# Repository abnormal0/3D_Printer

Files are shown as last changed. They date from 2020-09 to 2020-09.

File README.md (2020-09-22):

# 3D_Printer

3D Printer Designing @ June 2019

This is a project I did in 2019, which is a 3D printer, I used SolidWorks software to independently design the mechanical structure of the 3D printer, assisted in the design of the printer's motherboard circuit using Altium Designer, and assisted in the use of Clion as a IDE for embedded programming (C++), finally used Repetier-Host to test and print, the results are good.

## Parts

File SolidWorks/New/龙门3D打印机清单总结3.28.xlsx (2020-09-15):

关于现用200*200的3D打印机所需材料的总结
淘宝店 | 类型 | 规格 | 需要个数 | 单价 | 实际采购数量 | 总价 | 备注1 | 备注2 | 常用淘宝店家及链接
锦铝金属 (200以上开普票、以下不开） | 角块 | 2020 90度 | 8 | 1.5 | 8 | 12 |  |  | https://detail.tmall.com/item.htm?id=562060542375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
 |  | 2028 90度 | 4 | 1.8 | 4 | 7.2 | 垫底放电源备用
 |  | 45度 | 4 | 2.7 | 4 | 10.8 |  |  | https://detail.tmall.com/item.htm?id=562149318211&ns=1&abbucket=15&skuId=3701328155033
 | 船型螺母 | M4 | 4 | 0.3 | 10 | 3 |  |  | https://detail.tmall.com/item.htm?id=562124503053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
 |  | M5 | 85 | 0.35 | 100 | 35
 | 螺丝 | M4*30mm |  | 0.2 | 15 | 3 | 246.14 |  | https://detail.tmall.com/item.htm?id=563383555429&rn=71779688bedd88fad3f17ce4a9ea42f8&abbucket=8
 |  | M4*20mm |  | 0.2 | 20 | 4
 |  | M4*25mm |  | 0.2 | 10 | 2
 |  | M5*12mm |  | 0.15 | 70 | 10.5 | 用于铝型材固定
 |  | M5*8mm |  | 0.15 | 30 | 4.5
 |  | M5*16mm |  | 0.2 | 10 | 2
 |  | M5*10mm |  | 0.15 | 30 | 4.5
 | 覆盖板 | 2020 |  | 0.5 | 10 | 5 |  |  | https://detail.tmall.com/item.htm?id=562234523850&rn=545b0d162a0ad1bcf5be1794c23a67da&skuId=3694715830944
 |  | 2040 |  | 0.6 | 2 | 1
 | 角铝 | 80*80*6*1 |  |  | 1
 | 运费 |  |  |  |  | 9.4
瑞耐斯动力机械 （不开） | 立式轴承座 | KP08 | 10 | 2.85 | 10 | 28.5 |  |  | https://item.taobao.com/item.htm?spm=a1z10.1-c.w4004-18394139469.6.71c232e7foBqiQ&id=576786036687
 | 直线滑动滑块 | SCS8UU | 4 | 6.5 | 4 | 26 |  |  | https://item.taobao.com/item.htm?spm=a1z0d.7625083.1998302264.5.e4ab4e69x0ZOVJ&id=38524866174
 | 运费 |  |  |  |  | 10
坚威 （普票） | 外六角螺丝 | M3*8mm |  | 1.58 | 3 | 4.74 |  | 一包（10粒） | https://detail.tmall.com/item.htm?id=19278041723&rn=027d145cce653adb819a6ab926daf2c6&abbucket=8
 |  | M3*10mm |  | 1.68 | 2 | 3.36
 |  | M3*12mm |  | 1.78 | 2 | 3.56
 |  | M3*20mm |  | 2.28 | 1 | 2.28
 |  | M3*40mm |  | 3.7 | 1 | 3.7
 | 蝶形螺母 | M3 |  | 2 | 1 | 2 |  | 一包（10粒） | https://detail.tmall.com/item.htm?id=15466106343&rn=f1e7168ab5e2a042e206138b3402bcc0&abbucket=8
 | 外六角螺母 | M3 |  | 1.88 | 1 | 1.88 |  | 一包（20粒） | https://detail.tmall.com/item.htm?id=21253683169&rn=9e7bfd596e6b2c989f7e7b583f77c012&abbucket=8
 |  | M4 |  | 1.88 | 1 | 1.88
 |  | M5 |  | 1.28 | 2 | 2.56 |  | 一包（10粒）
 | 垫片 | M3*7*0.5mm |  | 1.38 | 1 | 1.38 | 限制：外径小于7.2mm | 一包（50粒） | https://detail.tmall.com/item.htm?id=18212096844&rn=48a5eeb54cd6bf01022148591b0d27cf&abbucket=8
 |  | M4*12*1mm |  | 1.88 | 1 | 1.88 | 限制：厚度为1mm
 |  | M5*10*1mm |  | 2.88 | 2 | 5.76 | 限制：厚度为1mm
 | 运费 |  |  |  |  | 5
大熊 （500以上开普票、以下开收据） | 电机座 | 42适配 | 2 | 1.85 | 2 | 3.7 | 第一件1.35 |  | https://item.taobao.com/item.htm?spm=a1z10.3-c.w4002-16808717495.11.21541f0fLYdBOu&id=550518493187
 | 挤出机套件 | 远程 1.75mm耗材 | 1 | 18 | 1 | 18 | 右手 |  | https://item.taobao.com/item.htm?spm=a1z10.3-c.w4002-16808717495.10.1a861f0f07pwb7&id=580259659280
 | 挤出电机 | 42 | 1 | 21 | 1 | 21 | 500mN扭力 |  | https://item.taobao.com/item.htm?spm=a1z10.5-c.w4002-16808717485.47.3ff449e79ndDr1&id=573837986187
 | 丝杆 | 8*450mm | 1 | 12.5 | 1 | 12.5 | 导程8mm 配丝杆螺母 |  | https://item.taobao.com/item.htm?spm=a1z10.5-c.w4002-16808717485.9.539649e7rQJ0iJ&id=549235947200
 |  | 8*400mm | 1 | 10.5 | 1 | 10.5
 |  | 8*350mm | 2 | 10 | 2 | 20 |  | 第一件9
 | 喷嘴套件 | V5,1.75*0.4mm | 1 | 22 | 1 | 22 | 远程 |  | https://item.taobao.com/item.htm?spm=a1z10.5-c.w4002-16808717485.23.4f0e3d3eUsWbog&id=566572427613
 | 光轴架 | 8mm | 11 | 2.05 | 11 | 22.55 | 第一件1.6 |  | https://item.taobao.com/item.htm?spm=a1z10.5-c.w4002-16808717485.12.63eb43actElVk8&id=549132170883
 |  | 16mm | 1 | 3.09 | 1 | 3.09
 | 同步轮 | 20齿 内径8 | 2 | 1.19 | 2 | 2.38 | 第一件0.69 |  | https://item.taobao.com/item.htm?spm=a1z10.3-c.w4002-16808717495.12.2b061f0fqClVBx&id=548608976808
 |  | 20齿 内径5 | 1 | 2.5 | 1 | 2.5 | 第一件2.5 |  | https://item.taobao.com/item.htm?spm=a1z10.5-c.w4002-16808717485.17.38405e43pdZeVO&id=548682226471
 |  | 不带齿 内径8 | 1 | 2.5 | 1 | 2.5
 | 同步带 | 600 | 1 | 4 | 1 | 4 |  |  | https://item.taobao.com/item.htm?spm=a1z10.5-c.w4002-16808717485.18.35847656tHOplc&id=548694206862
 | 丝杆螺母 | 导程8mm | 5 | 2.9 | 2 | 5.8 | 丝杆配了3个 |  | https://item.taobao.com/item.htm?spm=a1z10.5-c.w4002-16808717485.9.539649e7rQJ0iJ&id=549235947200
 | 热床 | 214*214 | 1 | 23 | 1 | 23 |  |  | https://item.taobao.com/item.htm?spm=a1z10.5-c.w4002-16808717485.35.413f77bfbgHAVP&id=550002989379
 | 联轴器 | 5mm*8mm | 2 | 2 | 2 | 4 | 第一件1.5 |  | https://item.taobao.com/item.htm?spm=a1z10.5-c.w4002-16808717485.22.6e7749e7yMqgn5&id=548882345967
 | 玻璃板 | 214*214*3mm | 1 | 9.5 | 1 | 9.5 |  |  | https://item.taobao.com/item.htm?spm=a1z10.5-c.w4002-16808717485.23.413f77bfbgHAVP&id=550065035441
 | 风扇 | 40*40*10mm | 1 | 1.3 | 1 | 1.3 |  |  | https://item.taobao.com/item.htm?spm=a1z10.5-c.w4002-16808717485.13.7a5c3b27watjqI&id=550262768093
 | 小猪佩奇风扇 |  | 1 | 11 | 1 | 11 |  |  | https://item.taobao.com/item.htm?spm=a1z10.5-c.w4002-16808717485.25.48bd3b27UXdbWK&id=550381735888
 | PE包线管 | 8mm | 1 | 3.2 | 1 | 3.2 |  |  | https://item.taobao.com/item.htm?spm=a1z10.3-c.w4002-16808717495.13.3cb31f0flchhTB&id=552765753763
 | 加热块套 | 黄 | 1 | 3 | 1 | 3 |  |  | https://item.taobao.com/item.htm?spm=a1z10.5-c.w4023-16808717484.7.6e7749e7yMqgn5&id=568588751287
 | 螺母座 | 内径8 | 4 | 6.58 | 4 | 26.32 | 第一件4.7 |  | https://item.taobao.com/item.htm?spm=a1z10.3-c.w4002-16808717495.9.7ffa1f0fHKth8f&id=564571287204
 | 椭圆直线轴承 | 内径8外径15 | 2 | 6.35 | 2 | 12.7 | 第一件5.6 |  | https://item.taobao.com/item.htm?spm=a1z10.3-c.w4002-16808717495.21.4c0b1f0fgFqwsL&id=557921686489
 | 氟龙管 | 2*3mm | 1 | 1.6 | 1 | 1.6 | 一份1m | 第一份1.6 | https://item.taobao.com/item.htm?spm=a1z0d.6639537.1997196601.3.7ea37484DQyn6M&id=549385220360
 | 电源 | 12V，20A，250W | 1 | 43 | 1 | 43 |  |  | https://item.taobao.com/item.htm?spm=a1z10.3-c.w4002-16808717495.18.60191f0fSX5zlX&id=550475946797
 | 运费 |  |  |  |  | 20
德西克 （普票） | 限位开关 | L型 | 2 | 18 | 3 | 54 | 5个包邮 |  | https://item.taobao.com/item.htm?id=580136528550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
 |  | U型 | 1 | 15 | 2 | 30
德轩电机 （普票） | 电机 | 42*60mm | 3 | 55 | 3 | 165 | 扭力0.9Nm，电流1.7A，引线30cm | 下单备注需要的电流 | https://item.taobao.com/item.htm?spm=a1z0d.6639537.1997196601.204.70377484EOUPLk&id=542770576889
 | 运费 |  |  |  |  | 11
奥格 （不开） | 光轴 | 8*375mm | 2 | - | 2 | 30 |  |  | https://item.taobao.com/item.htm?spm=a1z0d.6639537.1997196601.59.70377484EOUPLk&id=567224102575
 |  | 8*500mm | 2 | - | 2
 |  | 8*420mm | 2 | - | 2
东粤有色金属 （普票） | 铝板 | 20*60*2 | 2 | - | 实际采购300mm*60*2 |  | z轴底部轴承座垫高 | 先不买
 |  | 42*60*2 | 1 | - |  |  | 电机安装座
 |  | 95*40*2 | 2 | - | 实际采购250*40*2 |  | z轴顶部轴承座装配
 |  | 30*42*4 | 2 | - | 实际采购30*200*4 |  | x轴，连接底板和丝杆
 |  | 218*218*4 | 1 | - | 实际采购218*218*4 |  | 底板
东莞厂家 | 2020铝型材 | 290 | 2 |  |  |  | 底面宽
 |  | 490 | 2 |  |  |  | 底面长
 |  | 300 | 2 |  |  |  | 高
 |  | 420 | 1 |  |  |  | 龙门
 |  | 220 | 2
 |  | 188 | 1
 |  | 45度（210mm）
 | 4020铝型材 | 420 | 1 |  |  |  | 底
 | 角块 | 2028,90度角块 | 8
 | 步进电机驱动 | 4988 |  |  |  |  | 精度较低，适用于Z轴以及挤出机
 |  | 8825 |  |  |  |  | 精度较高，适用于X,Y轴
 | 5A大电流驱动 | LV8727
合计： |  |  |  |  |  | 817.52
附：未算运费和发票

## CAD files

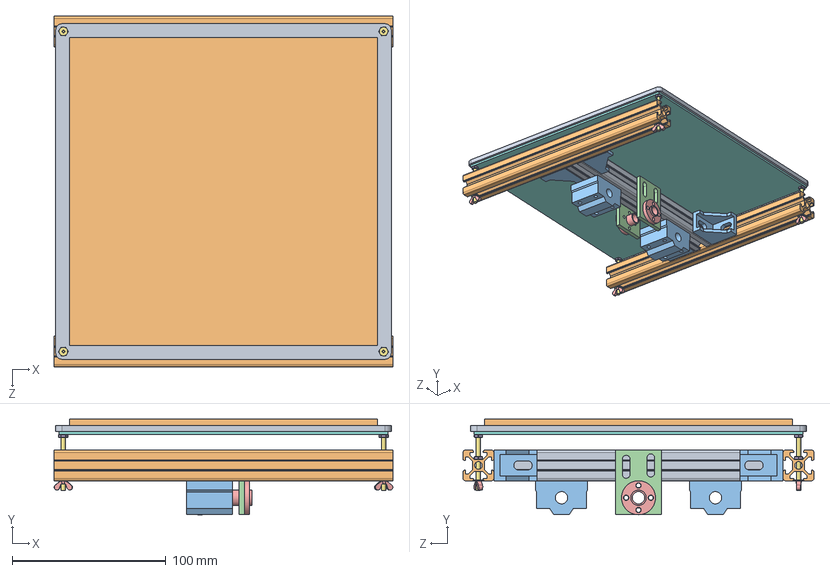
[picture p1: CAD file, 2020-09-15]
SolidWorks/New/底板装配.SLDASM
220.0 x 62.1 x 228.0 mm
2020角码 x 4
M3垫片 x 4
M3蝶形螺母 x 4
M3外六角螺母 x 8
M3_40mm外六角螺丝 x 4
热床
底板
玻璃板200-200-4
直线光杆滑轨 x 2
x轴铝片 x 2
丝杆螺母 x 2

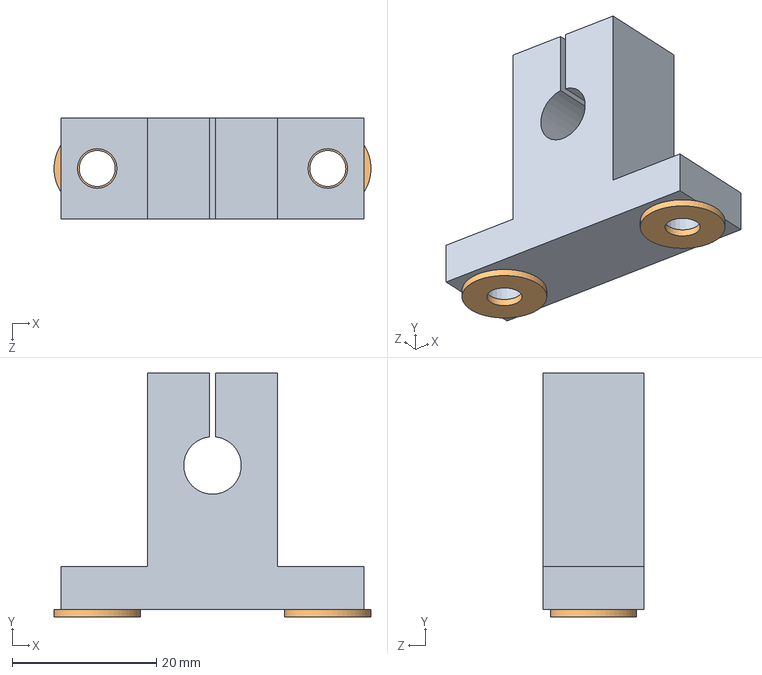
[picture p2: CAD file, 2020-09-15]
SolidWorks/New/光杆架垫片装配.SLDASM
44.0 x 33.8 x 14.0 mm
光杆架
光杆架垫片 x 2

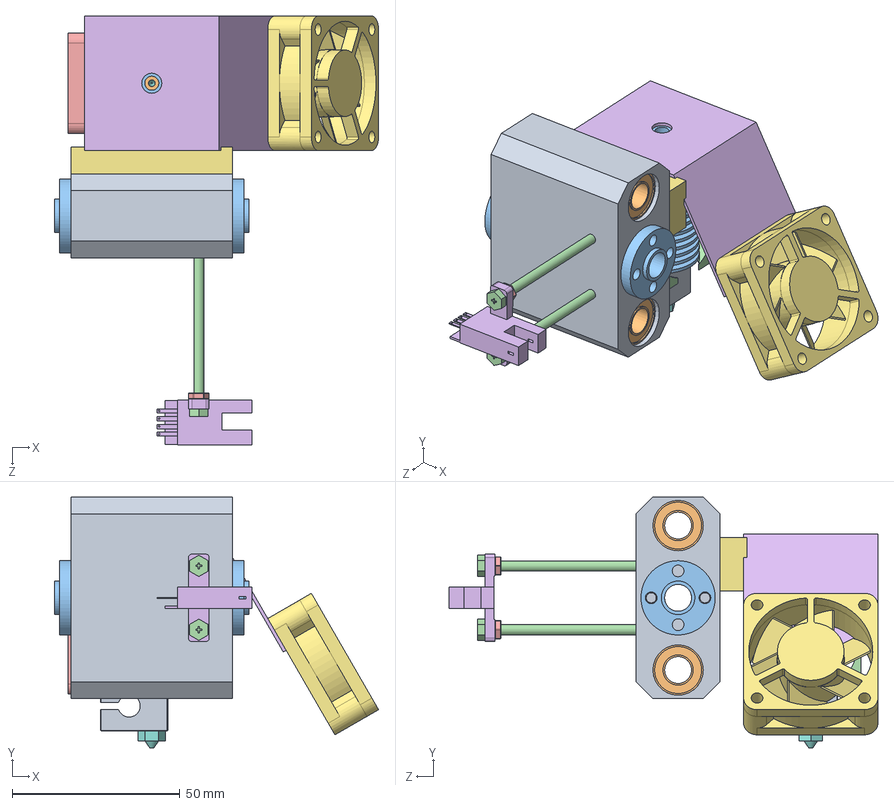
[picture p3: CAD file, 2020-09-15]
SolidWorks/New/y轴装配.SLDASM
96.5 x 74.7 x 127.7 mm
喷嘴固定件
直线轴承 x 2
丝杆螺母 x 2
M3_50mm外六角螺丝 x 2
M3外六角螺母 x 2
光电限位开关
喷头安装座
Nozzle 0.3mm^喷头装配
Heater_Block^喷头装配
Heatbreak^喷头装配
Heatsink^喷头装配
风扇固定
风扇3010
风扇固定片
风扇

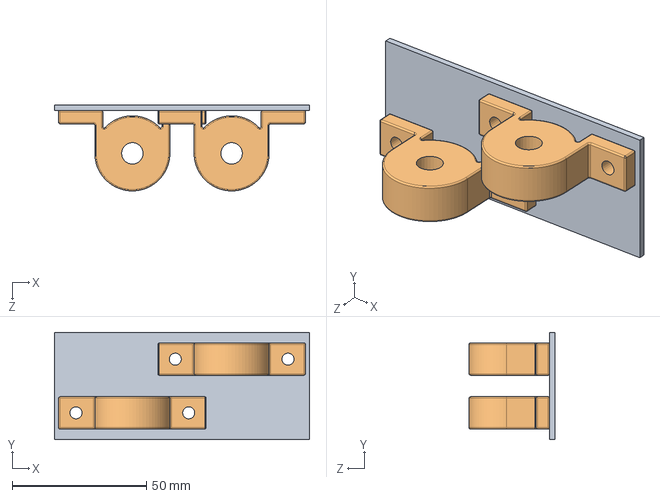
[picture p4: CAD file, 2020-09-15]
SolidWorks/New/立式轴承座右上装配.SLDASM
95.0 x 40.0 x 32.0 mm
立式轴承座右铝片
立式轴承座 x 2

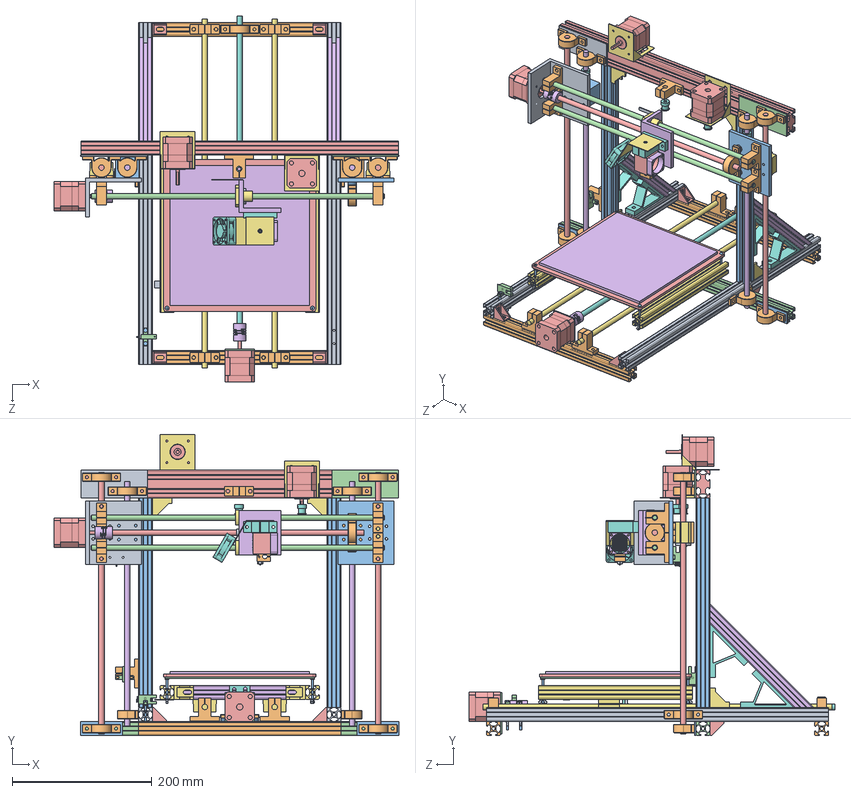
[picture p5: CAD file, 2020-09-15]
SolidWorks/New/新建打印机装配.SLDASM
494.0 x 431.3 x 524.0 mm
2020角码 x 8
2020角码-45度 x 4
立式轴承座左铝片
立式轴承座 x 10
立式轴承座下铝片 x 2
立式轴承座右铝片
小角件 x 6
M3垫片 x 6
M3蝶形螺母 x 6
M3外六角螺母 x 12
M3_40mm外六角螺丝 x 6
热床
底板
玻璃板200-200-4
直线光杆滑轨 x 4
x轴铝片 x 2
丝杆螺母 x 5
光杆架 x 10
光杆架垫片 x 26
42固定铝型材
42 motor x 4
联轴器 5-8-25 x 2
光杆x轴 x 2
丝轴x轴（无螺纹）
角铝
M4垫片 x 8
螺母座z轴限位
光电限位开关 x 3
光杆z轴 x 2
丝轴z轴（无螺纹） x 2
电机座 x 2
2GT-20齿同步轮 x 4
x轴限位片
螺母座
角铝右侧
光杆Y轴 x 2
丝轴y轴（无螺纹）
角铝中间
椭圆直线轴承 x 2
喷头安装座
Nozzle 0.3mm^喷头装配
Heater_Block^喷头装配
Heatbreak^喷头装配
Heatsink^喷头装配
风扇固定
风扇3010
风扇固定片
风扇
y轴限位片

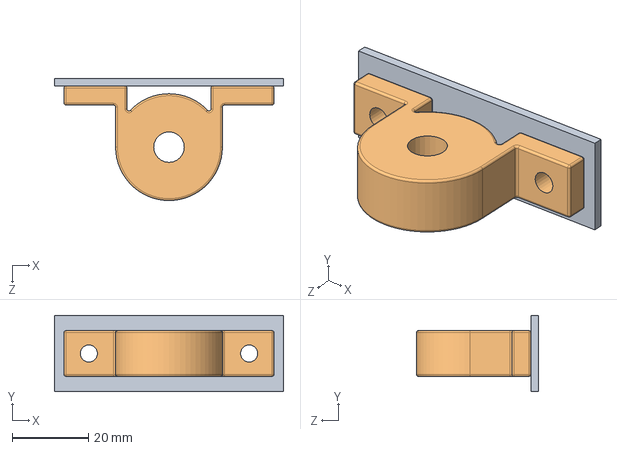
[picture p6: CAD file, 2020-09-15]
SolidWorks/New/立式轴承座下装配.SLDASM
60.0 x 20.0 x 32.0 mm
立式轴承座下铝片
立式轴承座

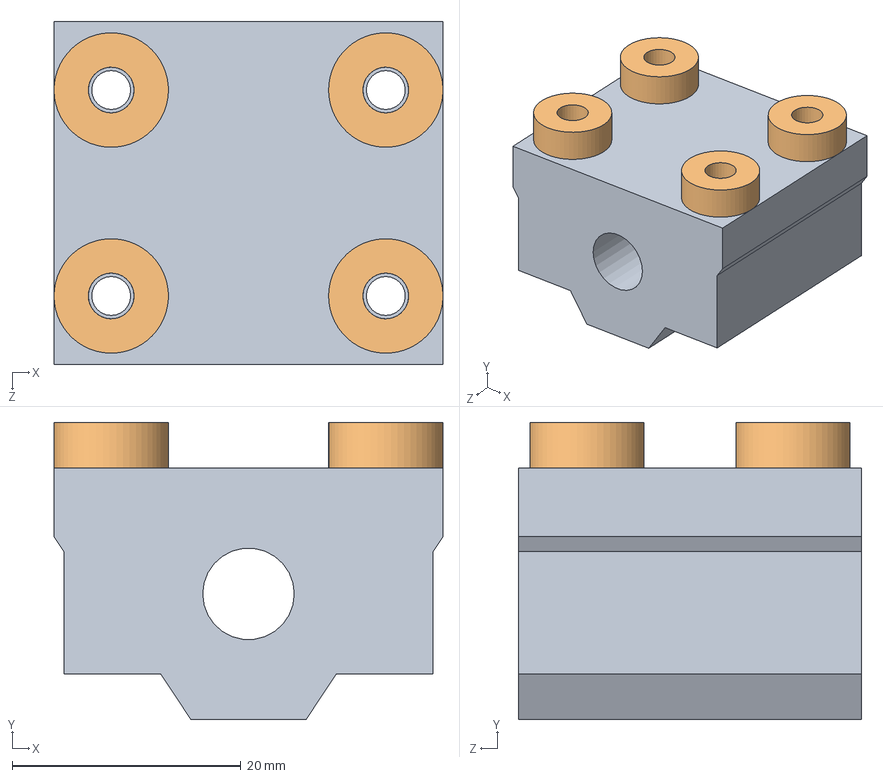
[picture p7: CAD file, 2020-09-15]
SolidWorks/New/直线滑块垫片装配.SLDASM
34.0 x 26.0 x 30.0 mm
直线光杆滑轨
M4垫片 x 4

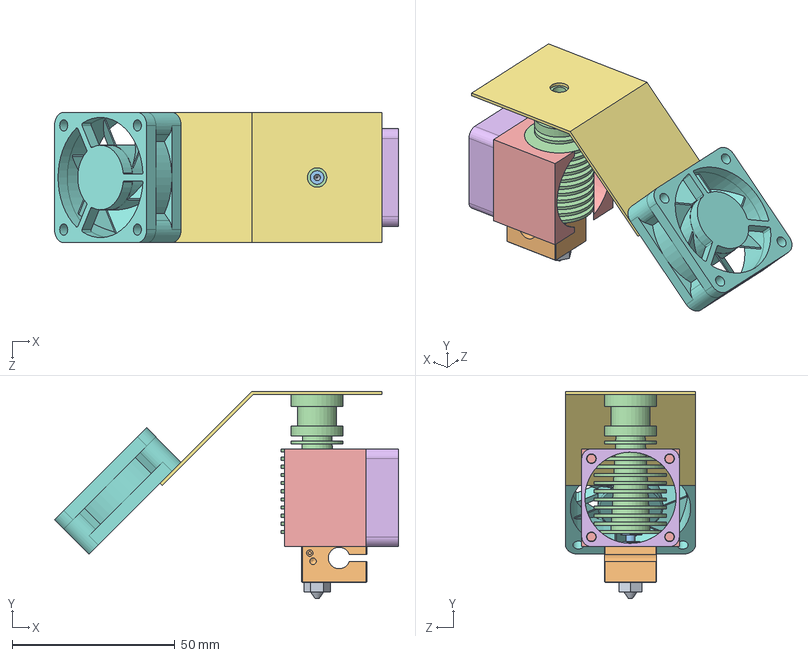
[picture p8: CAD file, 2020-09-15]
SolidWorks/New/喷头装配.SLDASM
105.7 x 63.7 x 40.0 mm
Nozzle 0.3mm^喷头装配
Heater_Block^喷头装配
Heatbreak^喷头装配
Heatsink^喷头装配
风扇固定
风扇3010
风扇固定片
风扇

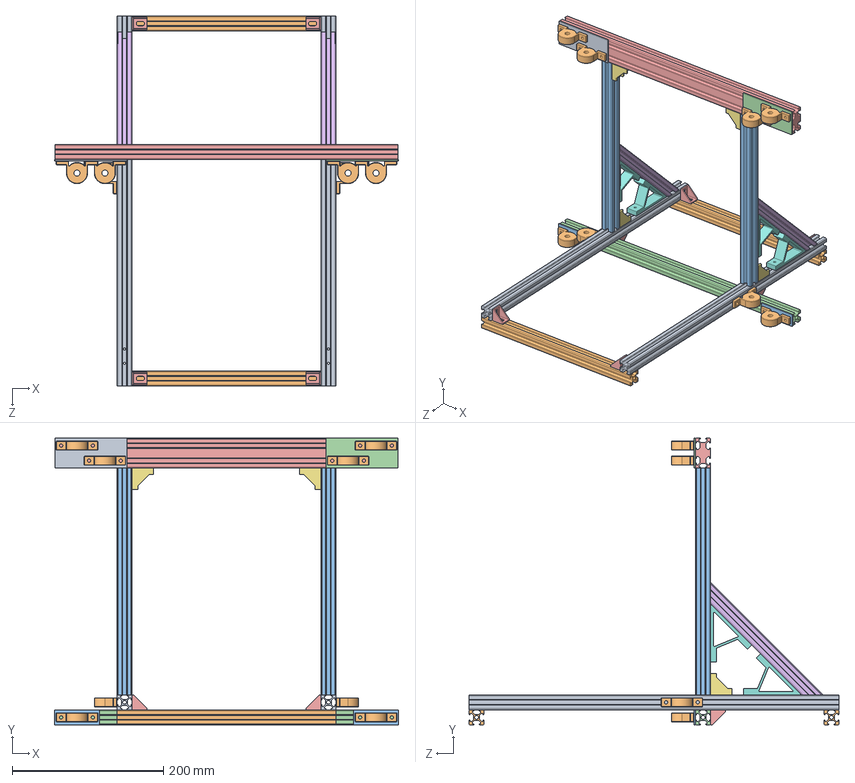
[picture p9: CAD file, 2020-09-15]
SolidWorks/New/铝型材框架装配.SLDASM
456.0 x 380.0 x 490.0 mm
2020角码 x 4
2020角码-45度 x 4
立式轴承座左铝片
立式轴承座 x 8
立式轴承座下铝片 x 2
立式轴承座右铝片
小角件 x 6

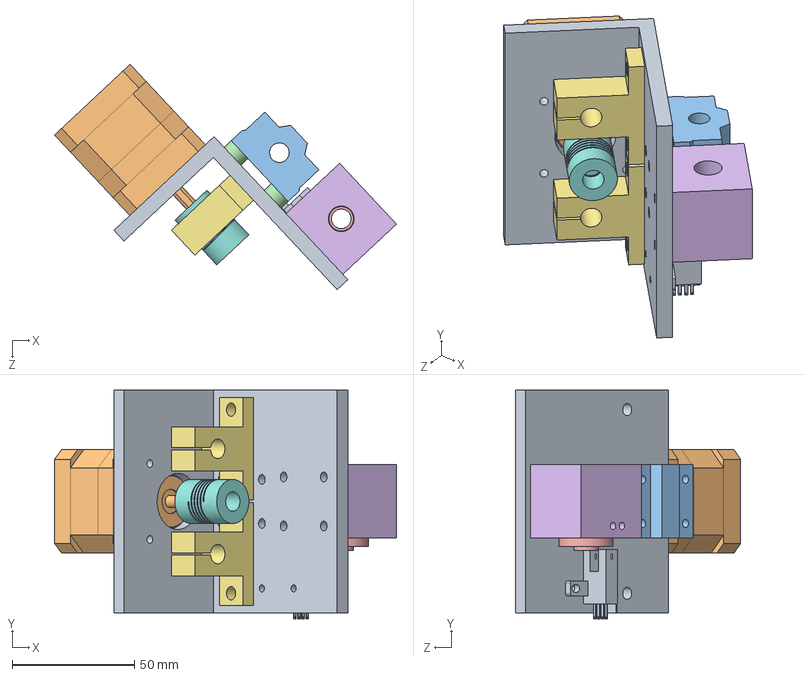
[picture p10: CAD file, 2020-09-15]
SolidWorks/New/y轴左侧装配.SLDASM
139.7 x 93.5 x 92.1 mm
角铝
42 motor
直线光杆滑轨
M4垫片 x 4
丝杆螺母
螺母座z轴限位
光杆架 x 2
联轴器 5-8-25
光电限位开关

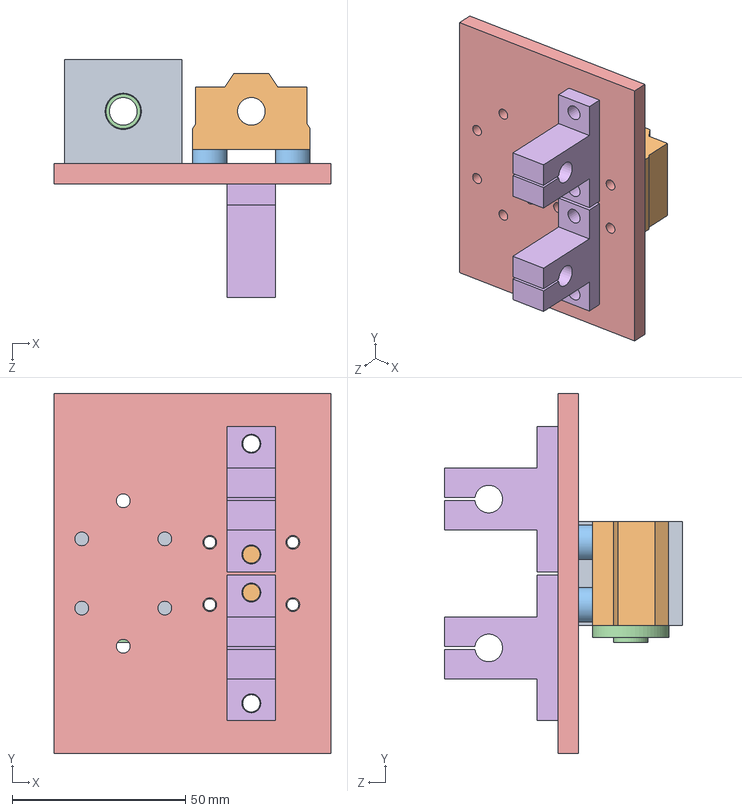
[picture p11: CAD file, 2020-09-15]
SolidWorks/New/y轴右侧装配.SLDASM
80.0 x 104.0 x 68.8 mm
螺母座
直线光杆滑轨
M4垫片 x 4
丝杆螺母
角铝右侧
光杆架 x 2

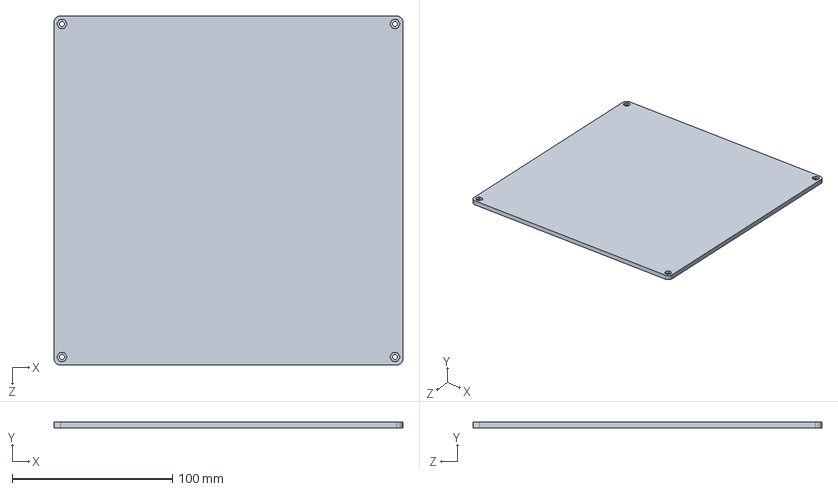
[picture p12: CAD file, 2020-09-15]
SolidWorks/New/底板.SLDPRT
218.0 x 4.00 x 218.0 mm

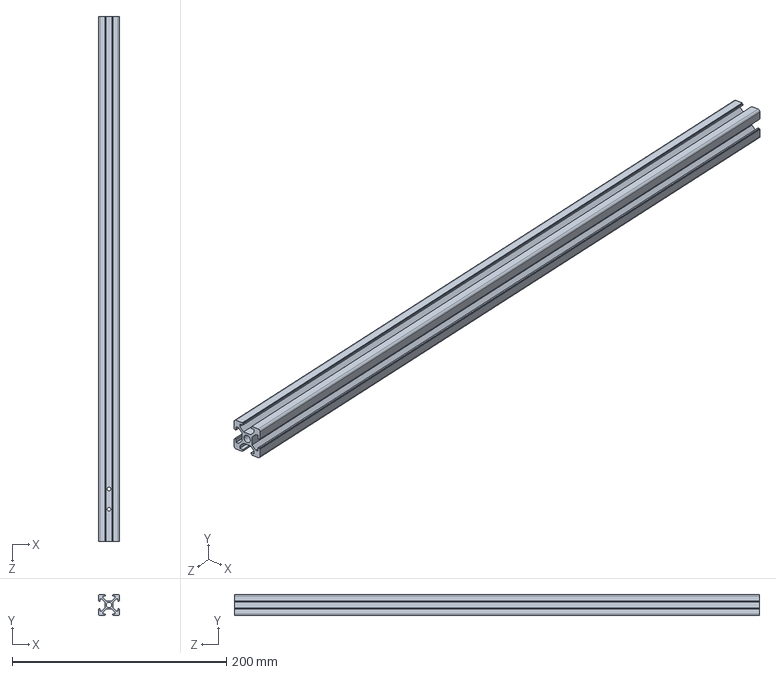
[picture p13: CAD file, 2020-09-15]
SolidWorks/New/铝型材角码/2020-490.SLDPRT
20.0 x 20.0 x 490.0 mm

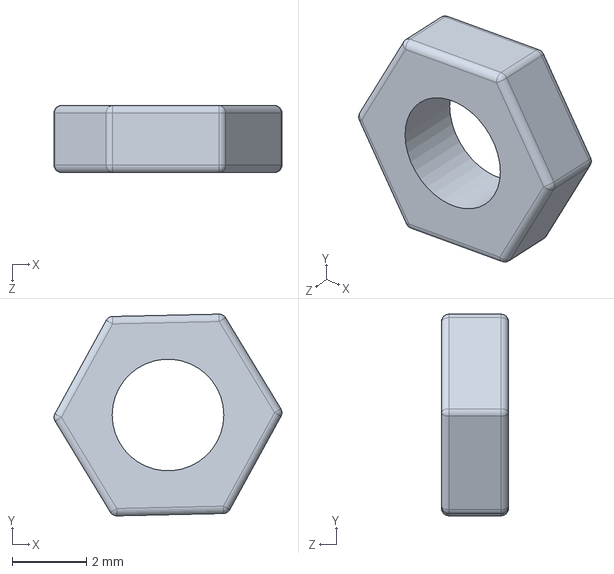
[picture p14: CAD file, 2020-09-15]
SolidWorks/New/M3外六角螺母.SLDPRT
6.13 x 5.42 x 1.80 mm

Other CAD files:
SolidWorks/New/立式轴承座左上装配.SLDASM
SolidWorks/New/铝型材角码/2020-210-45.SLDPRT
SolidWorks/New/螺母座.SLDPRT
SolidWorks/New/铝型材角码/2020-188.SLDPRT
SolidWorks/New/2020-188.SLDPRT
SolidWorks/New/2020-210-45.SLDPRT
SolidWorks/New/2020-220.SLDPRT
SolidWorks/New/2020-290.SLDPRT
SolidWorks/New/2020-300.SLDPRT
SolidWorks/New/2020-420.SLDPRT
SolidWorks/New/2020-490.SLDPRT
SolidWorks/New/2020角码-45度.SLDPRT
SolidWorks/New/2020角码.SLDPRT
SolidWorks/New/2040-290.SLDPRT
SolidWorks/New/2040-420.SLDPRT
SolidWorks/New/2GT-20齿同步轮.SLDPRT
SolidWorks/New/42 motor.SLDPRT
SolidWorks/New/42固定铝型材.SLDPRT
SolidWorks/New/M3_40mm外六角螺丝.SLDPRT
SolidWorks/New/M3_外六角螺丝.SLDPRT
SolidWorks/New/M3垫片.SLDPRT
SolidWorks/New/M3蝶形螺母.SLDPRT
SolidWorks/New/M4垫片.SLDPRT
SolidWorks/New/M4船型螺母.SLDPRT
SolidWorks/New/M5船型螺母.SLDPRT
SolidWorks/New/x轴铝片.SLDPRT
SolidWorks/New/x轴限位片.SLDPRT
SolidWorks/New/y轴限位片.SLDPRT
SolidWorks/New/z轴限位片.SLDPRT
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

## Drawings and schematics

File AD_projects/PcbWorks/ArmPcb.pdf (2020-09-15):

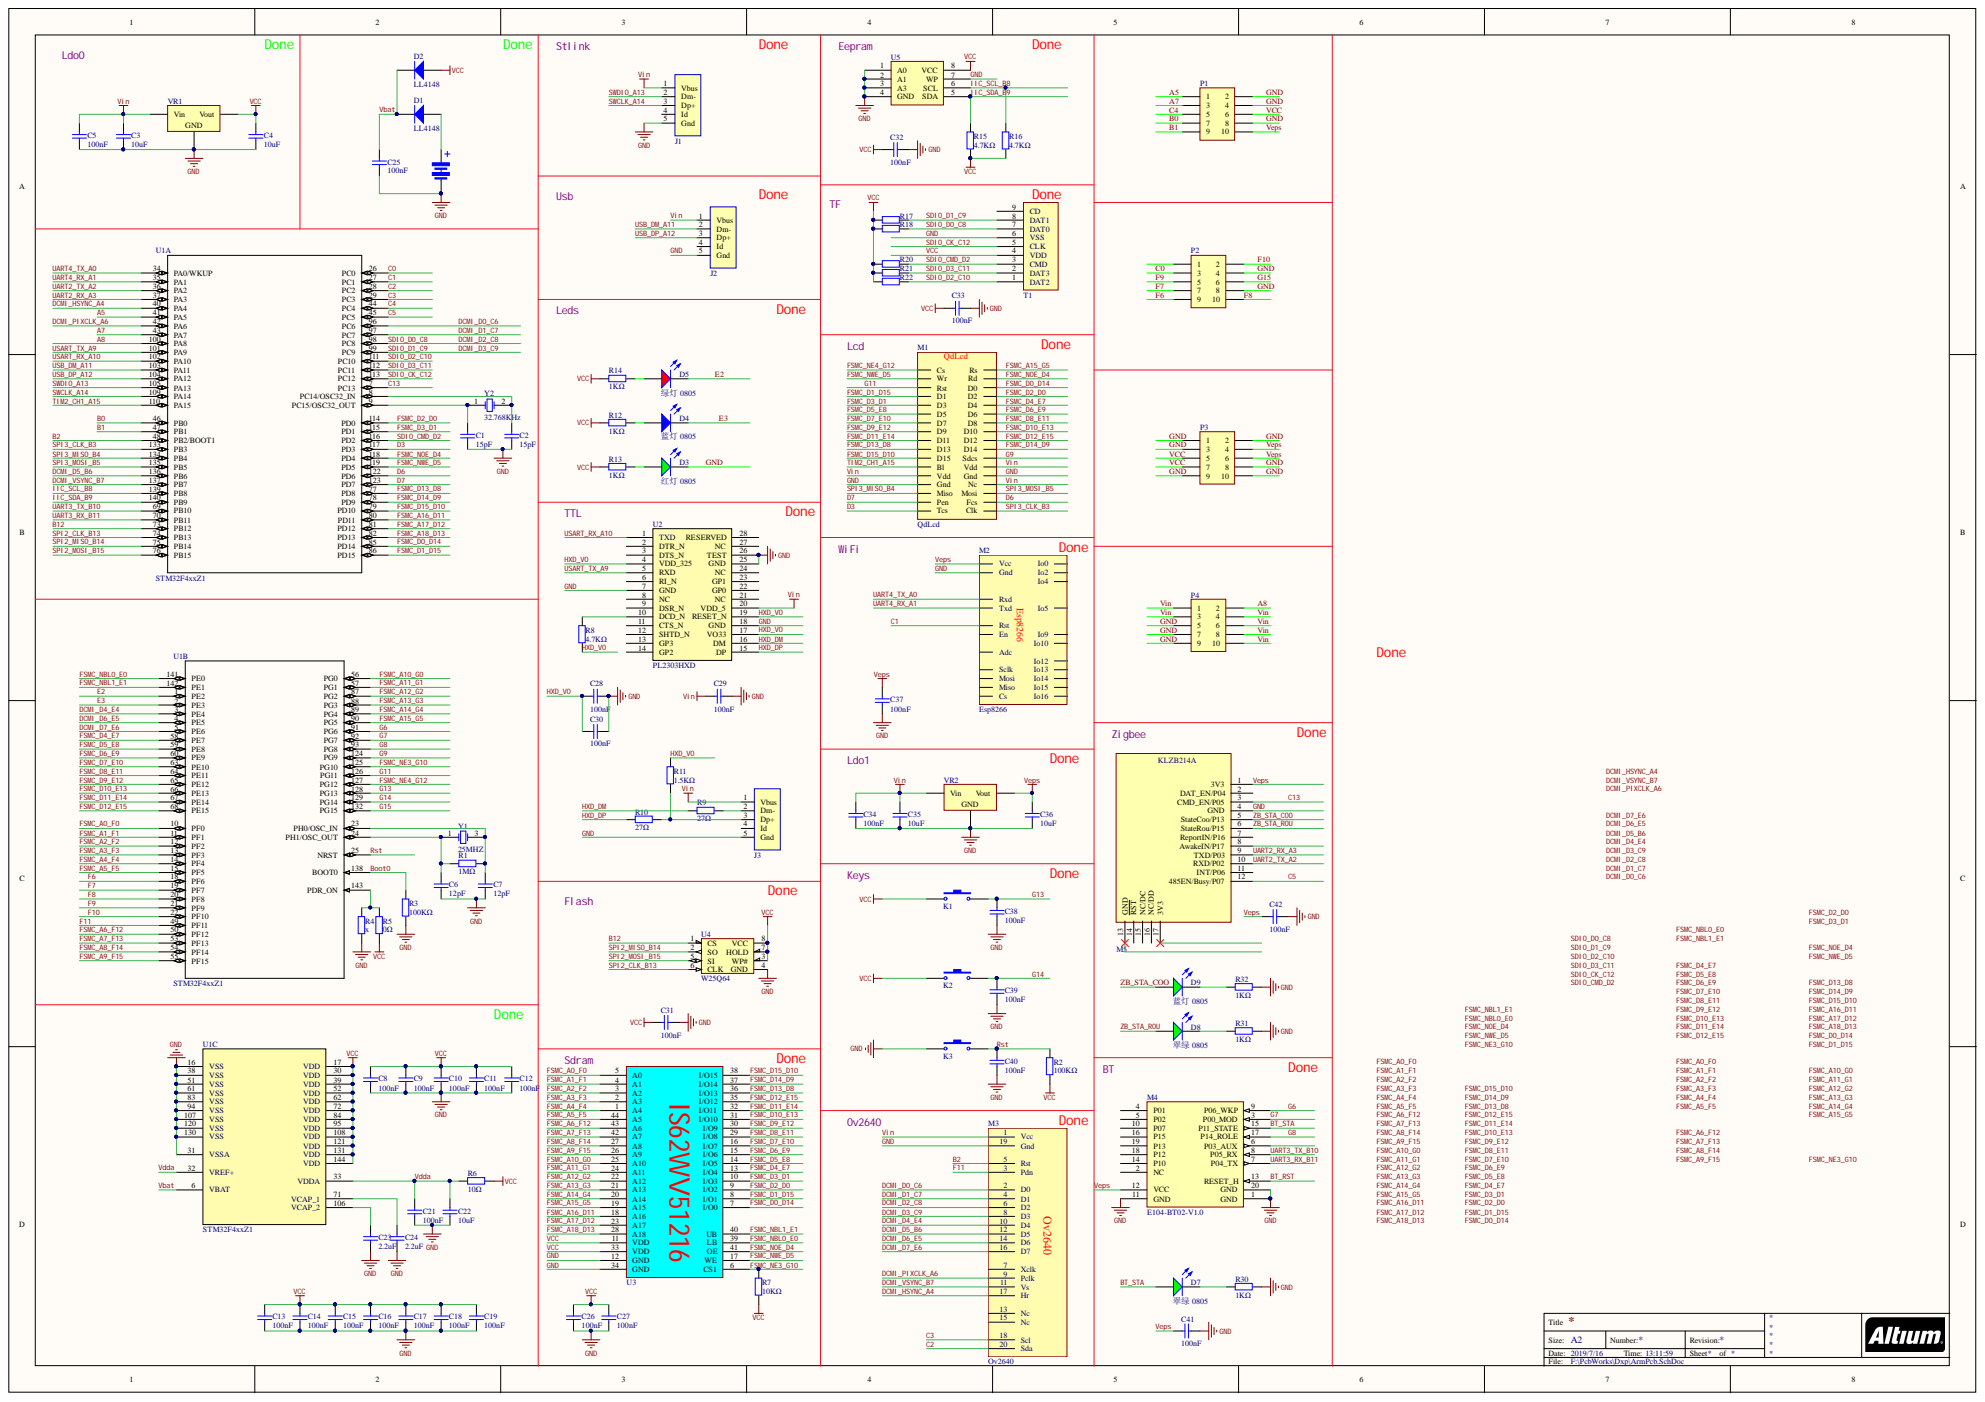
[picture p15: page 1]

VCC VCC GND GND

Date : Time : | | She e t * of *

A 2 | r : * | R evision: *

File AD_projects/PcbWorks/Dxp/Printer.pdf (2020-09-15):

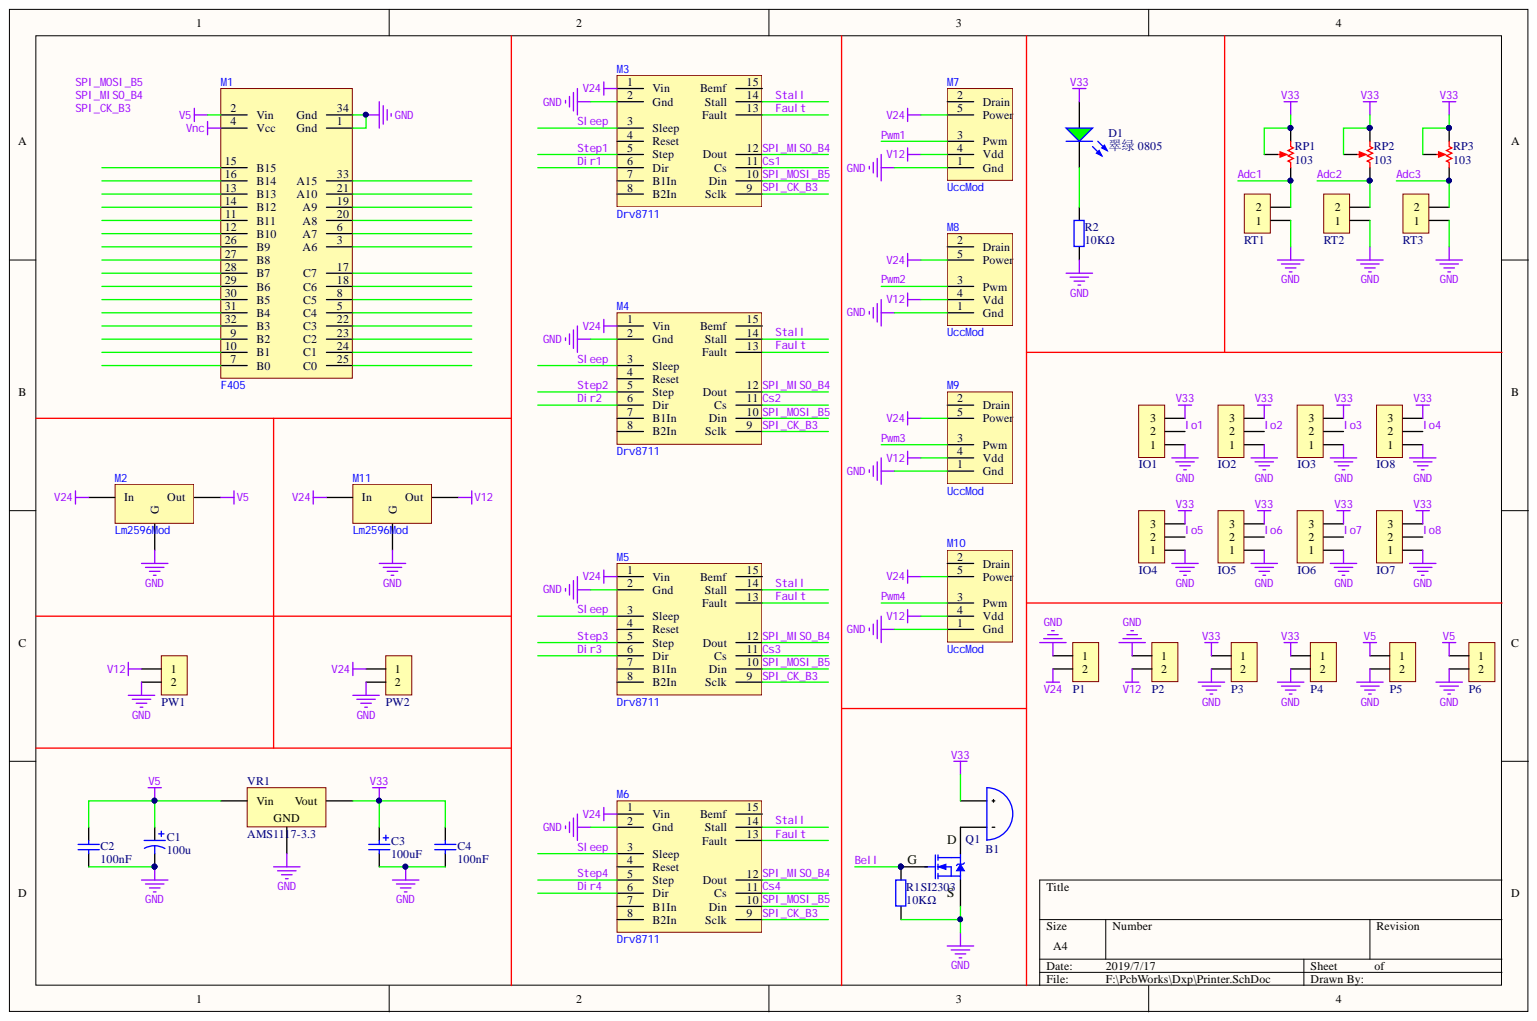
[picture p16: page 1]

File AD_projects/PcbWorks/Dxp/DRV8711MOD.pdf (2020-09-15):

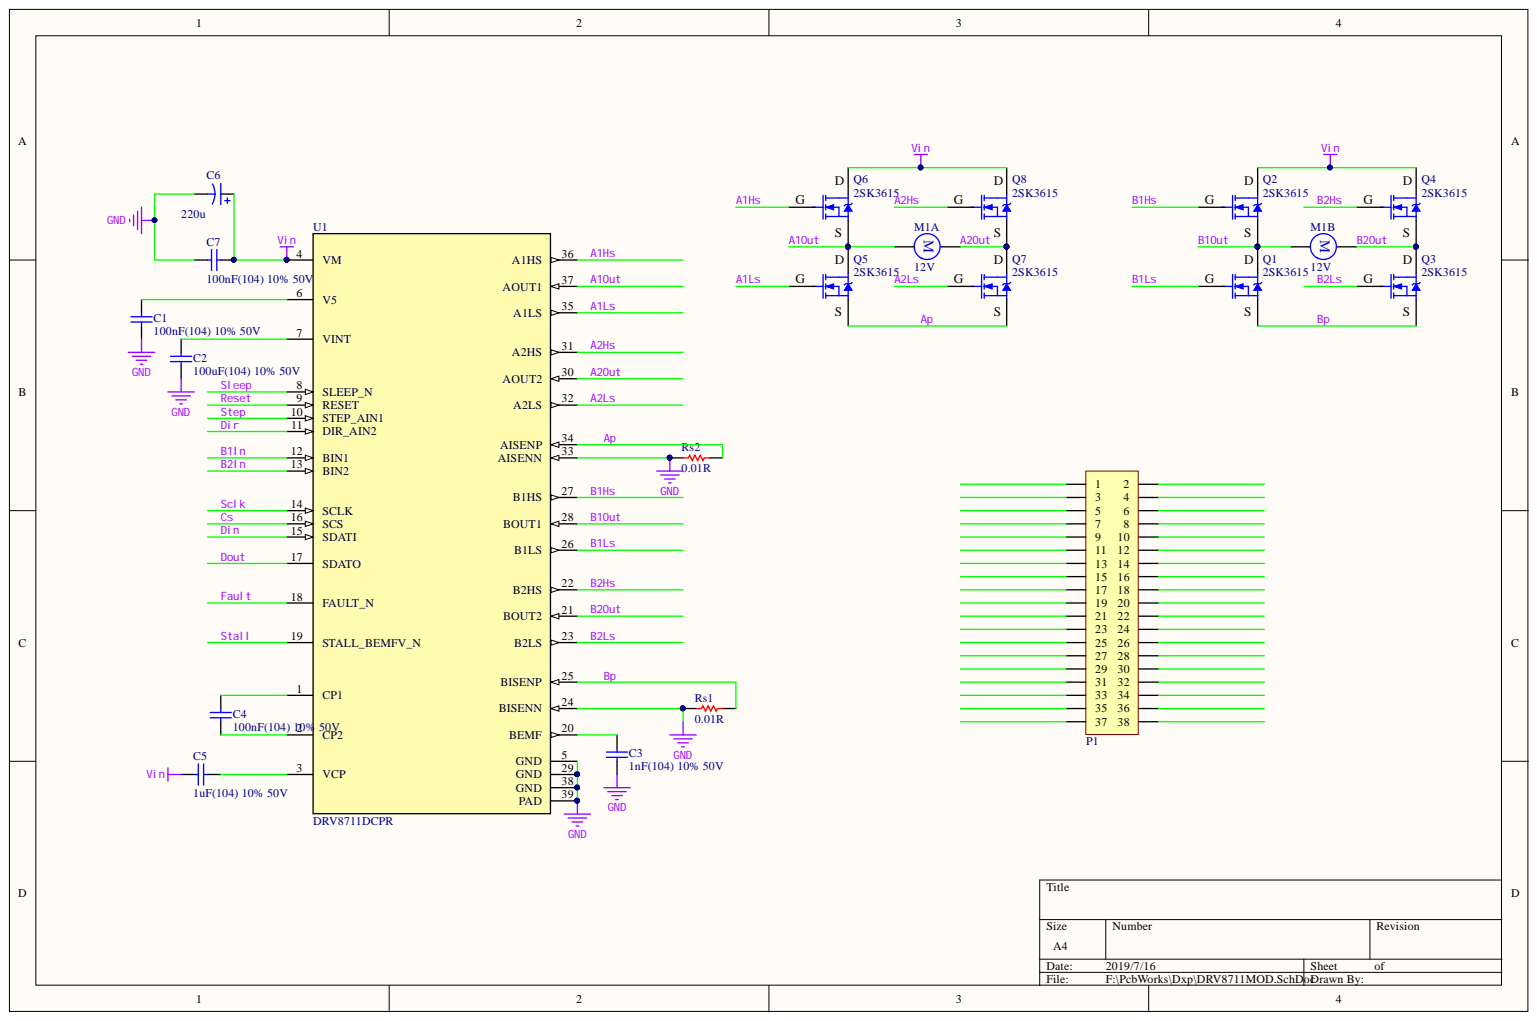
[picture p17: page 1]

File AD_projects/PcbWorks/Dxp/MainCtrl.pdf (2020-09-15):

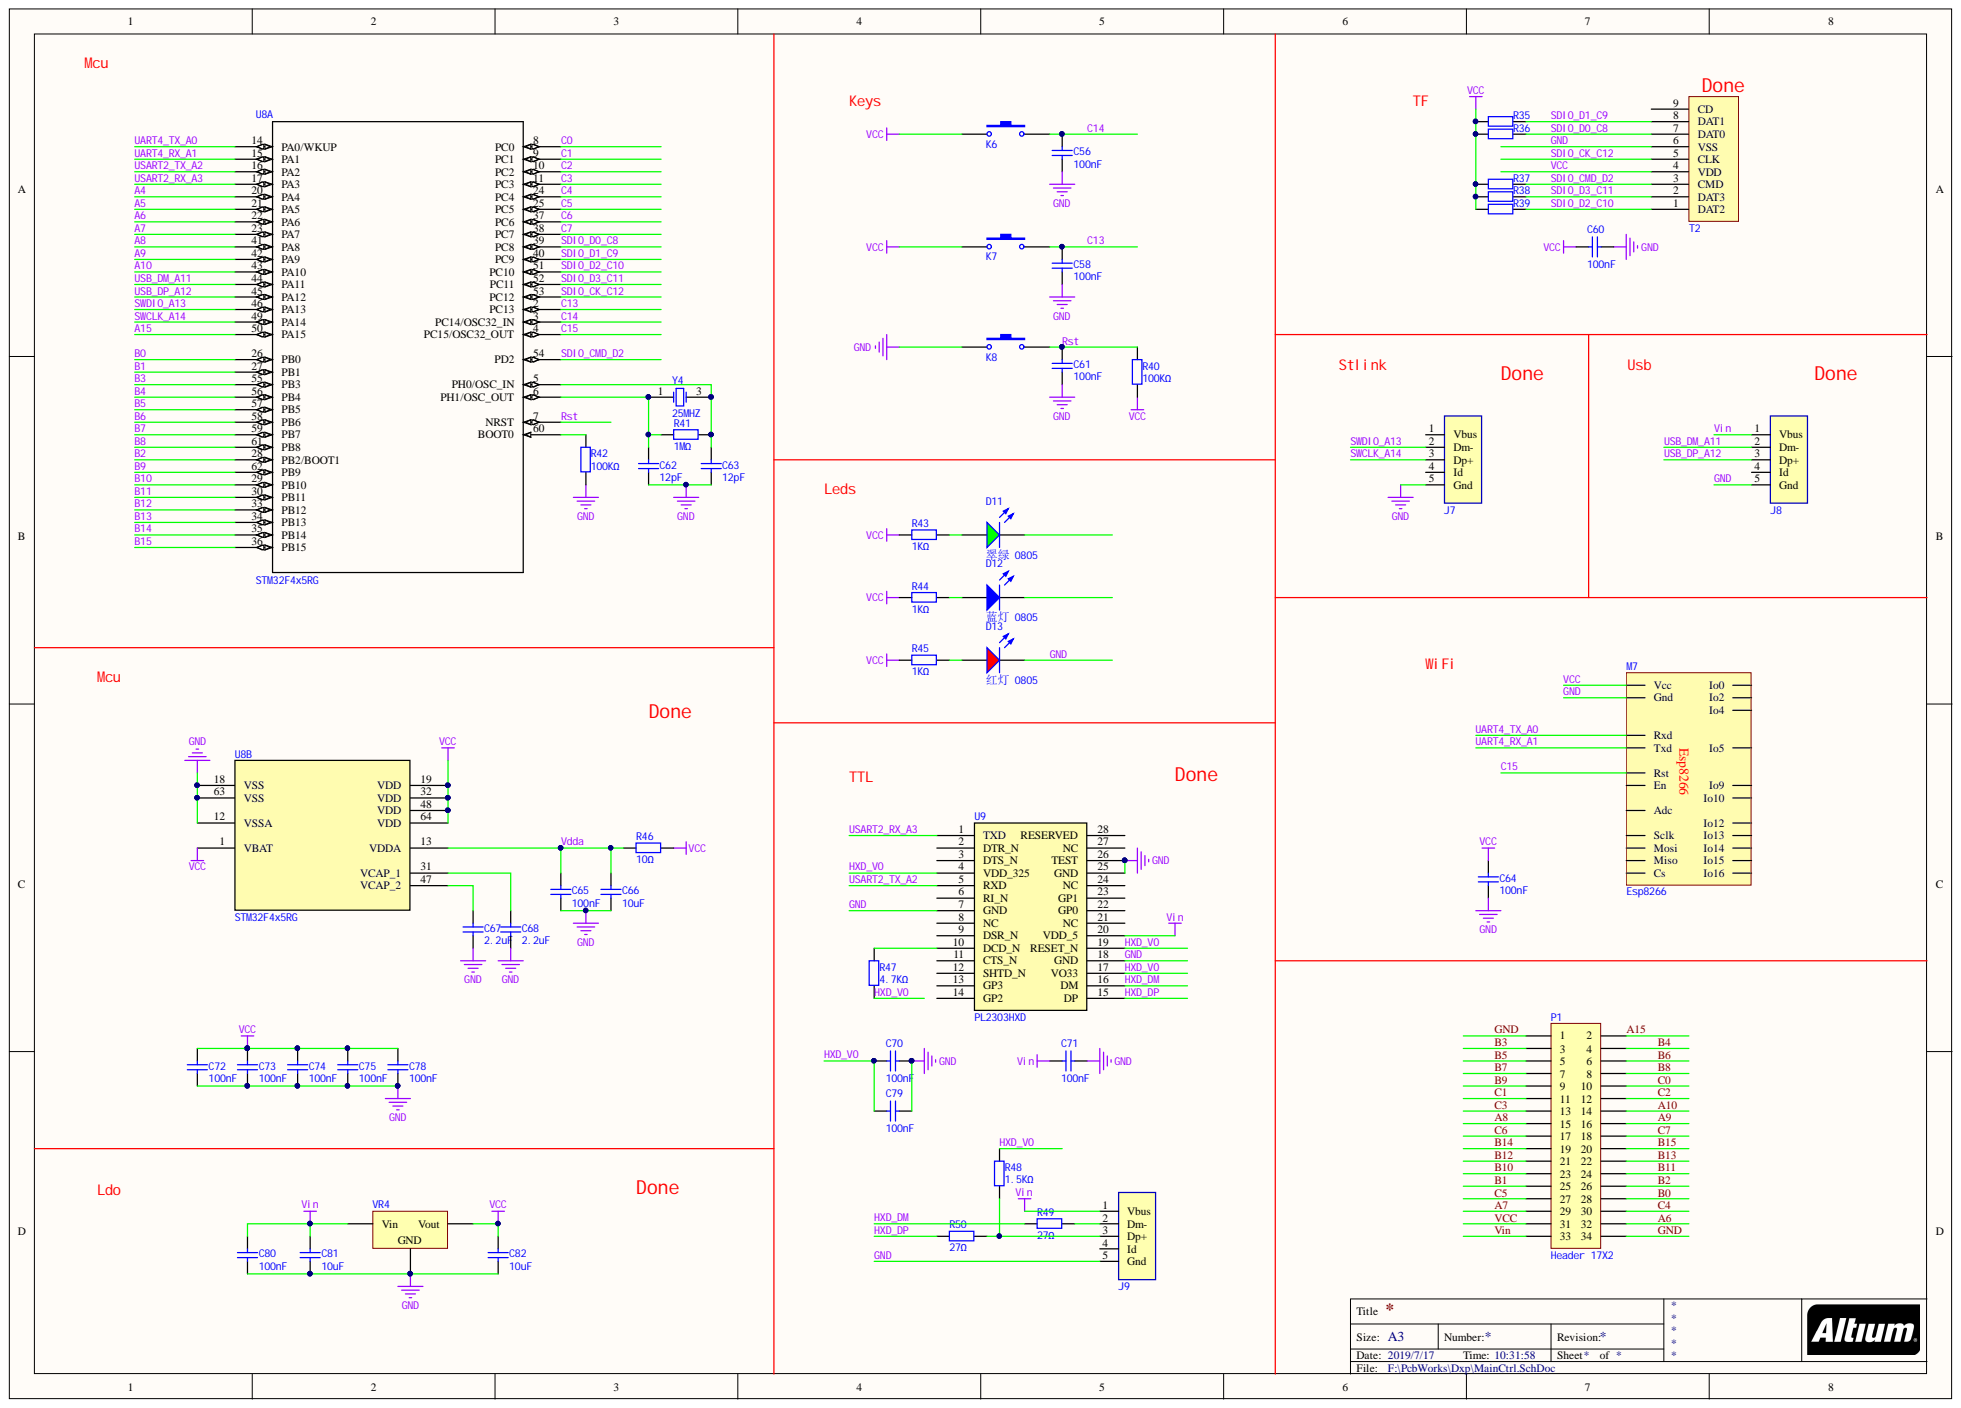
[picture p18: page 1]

Size: A 3 | Number : * | Revi s ion: *
Date: 2019/7/17 Ti me: 10:31:58 | | Sheet * of *

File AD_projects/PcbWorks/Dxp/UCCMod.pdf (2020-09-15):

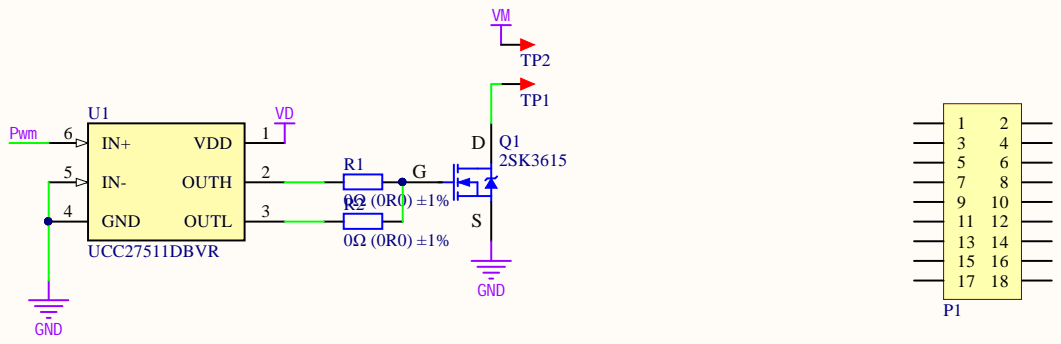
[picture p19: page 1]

Size: A4 | N umber: * | Rev i s i o n : *
Date: 2 0 1 9 / 7 / 1 7 T ime: 1 0 : 3 2 : 4 1 | | Sheet * o f *

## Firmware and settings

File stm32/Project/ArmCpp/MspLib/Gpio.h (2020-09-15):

//
// Created by Nc2016 on 2019/1/4.
//

#ifndef __GPIO_H
#define __GPIO_H

#include "Descriptor.h"

enum PIN
{
    Pin0 =1u<<0 ,
    Pin1 =1u<<1 ,
    Pin2 =1u<<2 ,
    Pin3 =1u<<3 ,
    Pin4 =1u<<4 ,
    Pin5 =1u<<5 ,
    Pin6 =1u<<6 ,
    Pin7 =1u<<7 ,
    Pin8 =1u<<8 ,
    Pin9 =1u<<9 ,
    Pin10=1u<<10,
    Pin11=1u<<11,
    Pin12=1u<<12,
    Pin13=1u<<13,
    Pin14=1u<<14,
    Pin15=1u<<15,
};

enum SPD
{
    Speed_Low=0u,
    Speed_Medium=1u,
    Speed_High=2u,
    Speed_Very_High=3u,
};


enum PULL
{
    No_Pull=0,
    Pull_Up=1,
    Pull_Down=2,
};

enum AFIO
{
    AF0_System             =0u,
    AF1_Tim1_2             =1u,
    AF2_Tim3_5             =2u,
    AF3_Tim8_11            =3u,
    AF4_Iic1_3             =4u,
    AF5_Spi1_2             =5u,
    AF6_Spi3               =6u,
    AF7_Usart1_3           =7u,
    AF8_Usart4_6           =8u,
    AF9_Can1_2_Tim12_14    =9u,
    AF10_OtgFs_Otg_Hs      =10u,
    AF11_Eth               =11u,
    AF12_Fsmc_Sdio_OtgHs   =12u,
    AF13_Dcmi              =13u,
    AF14_Ltdc              =14u,
    AF15_EventOut          =15u,
};


class Gpio
{
public:
    __IO u32 MODER;    /*!< GPIO port mode register,               Address offset: 0x00      */
    __IO u32 OTYPER;   /*!< GPIO port output type register,        Address offset: 0x04      */
    __IO u32 OSPEEDR;  /*!< GPIO port output speed register,       Address offset: 0x08      */
    __IO u32 PUPDR;    /*!< GPIO port pull-up/pull-down register,  Address offset: 0x0C      */
    __IO u32 IDR;      /*!< GPIO port input data register,         Address offset: 0x10      */
    __IO u32 ODR;      /*!< GPIO port output data register,        Address offset: 0x14      */
    __IO u32 BSRR;     /*!< GPIO port bit set/reset register,      Address offset: 0x18      */
    __IO u32 LCKR;     /*!< GPIO port configuration lock register, Address offset: 0x1C      */
    __IO u32 AFRL  ;   /*!< GPIO alternate function registers,     Address offset: 0x20-0x24 */
    __IO u32 AFRH  ;   /*!< GPIO alternate function registers,     Address offset: 0x20-0x24 */

    void OutPp(u32 pin);

    void OutOd(u32 pin);

    void Down(u32 b);

    void Up(u32 b);

    void AfPp(u32 pin);

    void Speed(u32 pin, SPD speed);

    void Pull(u32 pin, PULL pull);

    void Alternate(u32 pin, AFIO af);

    void Anal(u32 pin);

    void In(u32 pin);
};

#define GPIOA                 ((Gpio *) 0x40020000U)
#define GPIOB                 ((Gpio *) 0x40020400U)
#define GPIOC                 ((Gpio *) 0x40020800U)
#define GPIOD                 ((Gpio *) 0x40020C00U)
#define GPIOE                 ((Gpio *) 0x40021000U)
#define GPIOF                 ((Gpio *) 0x40021400U)
#define GPIOG                 ((Gpio *) 0x40021800U)
#define GPIOH                 ((Gpio *) 0x40021C00U)
#define GPIOI                 ((Gpio *) 0x40022000U)


#endif //HELLO_GPIO_H

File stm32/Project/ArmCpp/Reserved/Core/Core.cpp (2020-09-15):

//
// Created by Nc2016 on 2019/1/4.
//

#include "Msp.h"
#include "UsartBuffer.h"
#include "Main.h"

extern u8 USART_Area[];

static void RccInit(void);
static void NvicInit(void);
static void PerEnable(void);
static void PerInit(void);

void GpioInit();

extern "C"
void Core(void)
{
    RccInit();
    NvicInit();
    PerEnable();
    GpioInit();
    PerInit();
}

void NvicInit(void)
{
    M4.NvicGroup(Group_4);
    M4.NvicPri(PendSV_IRQn,15,0);
    M4.NvicPri(SysTick_IRQn,0,0);
    M4.NvicPri(USART2_IRQn,13,0);
    M4.NvicPri(TIM7_IRQn,14,0);
    M4.NvicPri(ADC_IRQn,12,0);

}


static void RccInit()
{

    //Power Set to Scale1
    RCC->APB1Enable(APB1_Power);
    PWR->Scale(Power_Scale1);

    //Set Flash Wait Cycles
    FLASH->WaitCycles(3);


    //Pll Config
    RCC->HseOn();
    RCC->Pll(25, 288, 2,6);
    RCC->PllOn();


    //System Clock Config
    RCC->Clk(AHB_Clk_Div1, APB_Clk_Div4, APB_Clk_Div2, Clk_Src_Pll);
}

static void PerEnable()
{
    RCC->AHB1Enable(AHB1_GpioA);
    RCC->AHB1Enable(AHB1_GpioB);
    RCC->AHB1Enable(AHB1_GpioC);
    RCC->AHB1Enable(AHB1_GpioD);
    RCC->AHB1Enable(AHB1_GpioE);
    RCC->APB2Enable(APB2_Adc1);
    RCC->APB2Enable(APB2_Sdio);
    RCC->AHB1Enable(AHB1_DMA1);
    RCC->AHB1Enable(AHB1_DMA2);

    RCC->APB1Enable(APB1_Tim7);
    RCC->APB1Enable(APB1_Tim3);
    RCC->APB1Enable(APB1_Tim6);
    RCC->APB1Enable(APB1_Usart2);
}

void PerInit()
{

    DMA1->DS5.DateNum(USART_AREA_SIZE);
    DMA1->DS5.Mem0Addr((u32)(USART_Area));
    DMA1->DS5.PerAddr((u32) &(USART2->DR));

    DMA1->DS5.Select(Ch4);
    DMA1->DS5.Priority(Priority0);
    DMA1->DS5.MemSet(Mem8, Mem_Inc);
    DMA1->DS5.PerSet(Per8, Per_Fix);
    DMA1->DS5.Dir(Per_To_Mem);
    DMA1->DS5.Circular(False);
    DMA1->DS5.FlowCtrl(Per_Ctrl);
    DMA1->DS5.Start();

    USART2->Reset();
    USART2->Baud(115200);

    USART2->CR1 |= 1 << 4;
    USART2->CR3 |= 1 << 6;

    USART2->Enable(Tx_Rx_Both);
    USART2->PrintLn("System Init...");


    SDIO->ClockDiv(120);
    SDIO->RiEdge(True);
    SDIO->ClkPass(False);
    SDIO->PowerSave(False);
    SDIO->BusWide(Sdio_Bus_4b);
    SDIO->FlowCtrl(False);
    SDIO->PowerOn();
    SDIO->ClkOn();

    SDIO->DTIMER = 0XFFFFFFFFU;
    SDIO->DLEN = 512;

    DMA2->DS0.DateNum(ADC_AREA_LEN);
    DMA2->DS0.Mem0Addr((u32)(Adc_Area));
    DMA2->DS0.PerAddr((u32) &(ADC1->DR));

    DMA2->DS0.Select(Ch0);
    DMA2->DS0.Priority(Priority1);
    DMA2->DS0.MemSet(Mem16, Mem_Inc);
    DMA2->DS0.PerSet(Per16, Per_Fix);
    DMA2->DS0.Dir(Per_To_Mem);
    DMA2->DS0.Circular(True);
    DMA2->DS0.FlowCtrl(Dma_Ctrl);
    DMA2->DS0.Start();

    ADC1->Mode(True,False);
    ADC1->Iqr(True);
    ADC1->EocEach(False);
    ADC1->Dma(True);

    ADC1->Group(2);
    ADC1->Ch(0,8);
    ADC1->Ch(1,9);

    ADC1->ExtTri(True,False);
    ADC1->TriEven(Trigger_Timer3_CH1);

    ADC1->On();
    //ADC1->Start();

    TIM3->CR1 |= TIM_CR1_ARPE;
    TIM3->CCMR1|=7<<4;   //CH2 PWM2模式
    TIM3->CCMR1|=1<<3;   //CH2预装载使能
    TIM3->ARR=99;           //设定计数器自动重装值
    TIM3->PSC=7499;                //预分频器不分频
    TIM3->CCR1=49;         //设置占空比
    TIM3->CCER|=1;     //OC2 输出使能
    TIM3->CR1|=0x01;      //使能定时器2
}

void GpioInit()
{
    GPIOA->OutOd(4);
    GPIOA->OutOd(5);
    GPIOA->Up(4);
    GPIOA->Up(5);

    GPIOB->OutPp(12);
    GPIOB->Down(12);

    GPIOA->AfPp(2);
    GPIOA->Speed(2, Speed_Very_High);
    GPIOA->Pull(2, Pull_Up);
    GPIOA->Alternate(2, AF7_Usart1_3);

    GPIOA->AfPp(3);
    GPIOA->Speed(3, Speed_Very_High);
    GPIOA->Pull(3, Pull_Up);
    GPIOA->Alternate(3, AF7_Usart1_3);

    GPIOC->AfPp(8);
    GPIOC->AfPp(9);
    GPIOC->AfPp(10);
    GPIOC->AfPp(11);
    GPIOC->AfPp(12);
    GPIOD->AfPp(2);

    GPIOC->Speed(8, Speed_Very_High);
    GPIOC->Speed(9, Speed_Very_High);
    GPIOC->Speed(10, Speed_Very_High);
    GPIOC->Speed(11, Speed_Very_High);
    GPIOC->Speed(12, Speed_Very_High);
    GPIOD->Speed(2, Speed_Very_High);

    GPIOC->Alternate(8, AF12_Fsmc_Sdio_OtgHs);
    GPIOC->Alternate(9, AF12_Fsmc_Sdio_OtgHs);
    GPIOC->Alternate(10, AF12_Fsmc_Sdio_OtgHs);
    GPIOC->Alternate(11, AF12_Fsmc_Sdio_OtgHs);
    GPIOC->Alternate(12, AF12_Fsmc_Sdio_OtgHs);
    GPIOD->Alternate(2, AF12_Fsmc_Sdio_OtgHs);

    GPIOB->Anal(0);
    GPIOB->Anal(1);
}
